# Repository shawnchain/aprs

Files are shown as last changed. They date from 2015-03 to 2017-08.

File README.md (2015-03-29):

# TinyAPRS - A cheap APRS TNC for HAM #

### What is TinyAPRS ###

Like most of the APRS TNCs, TinyAPRS is an AFSK1200 modem that decodes radio signals into AX25 data packets. TinyAPRS also supports KISS protocol, so you can use it with most of the APRS applications.

Unlike most of the APRS TNCs, tinyAPRS is VERY VERY CHEAP. It will only cost $10 to build one. That means you can build your own APRS IGATE or tracking beacon with very low cost.

TinyAPRS has good performance on decoding. 
Currently, it works perfectly with my GM300 radio and decodes packets successfully from OT++(The local Digipeater)/FTM350R(My Car) and other devices. Based on my test, it decodes 850+ records from WA8LMF APRS TestCD/Track1. 

### How did it work ###

TinyAPRS is built on the giants shoulder.

 - An ALC/Filter circut that is the same as OpenTracker used, which will  greatly improve the decode capability.(Thank you to BH4TDV for sharing the circut design)
 - A fine-tunned AFSK/AX25/KISS stack that runs on AVR chip with very small memory footprints. (Thank you to Mark Qvist for his MicroAPRS, but mine now is better :)
 - Good abstraction to the hardware with BertOS, which made it easy to port TinyAPRS firmware to other MCUs.

Technical specification 

 - Main Chip : ATMEL/ATMEGA328P (Cheap clones of Arduino ProMini, could be ported to other type of AVR MCUs with ease)
 - ALC circut: MCP6001 OPA
 - Firmware  : AFSK1200/KISS(P-CSMA)/AT Serial

### The License ###

TinyAPRS is released under GPL license, **but with the following restriction** :

 - Any person, who decide to use and/or get benefits from any part of the TinyAPRS project, will be obliged to send the author(me/BG5HHP/Shawn) a gift. (Any kind of gift will be fine but Beers/PostCards/Parts of HAM radios are preferred :)
 - No commercial use.
 - All GPL restrictions

### Pictures ###

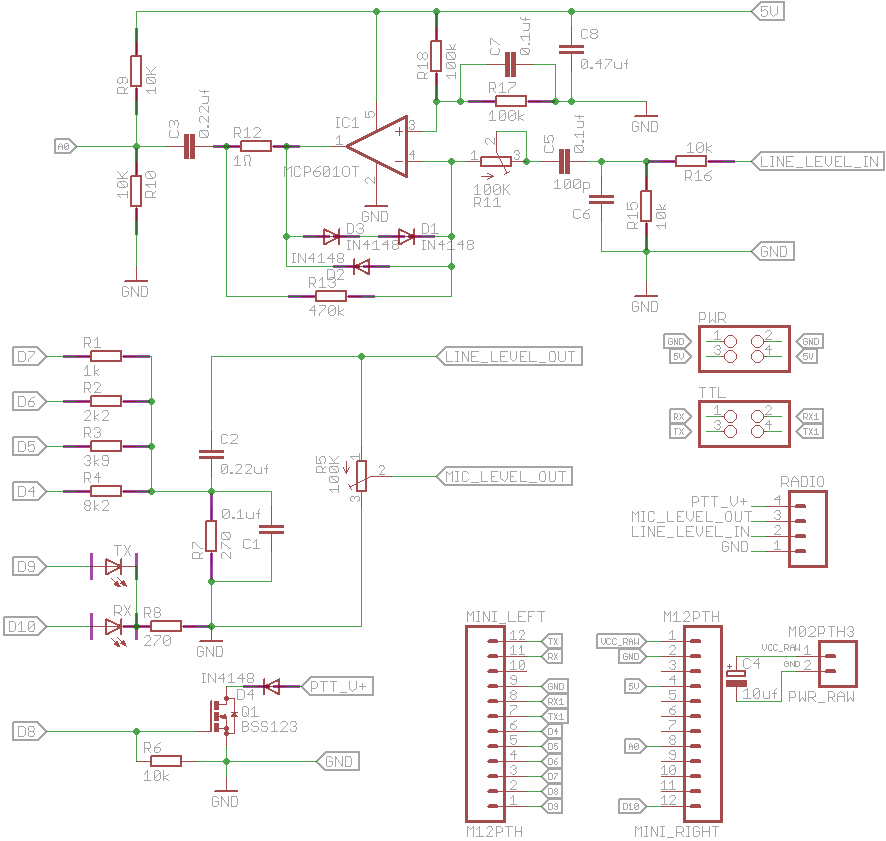
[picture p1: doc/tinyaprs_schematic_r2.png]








Please visit my [weibo album](http://www.weibo.com/p/1005052321043580/album?from=page_100505&mod=TAB#place "Weibo Album") for more pictures.

Cheers,

Shawn (BG5HHP)

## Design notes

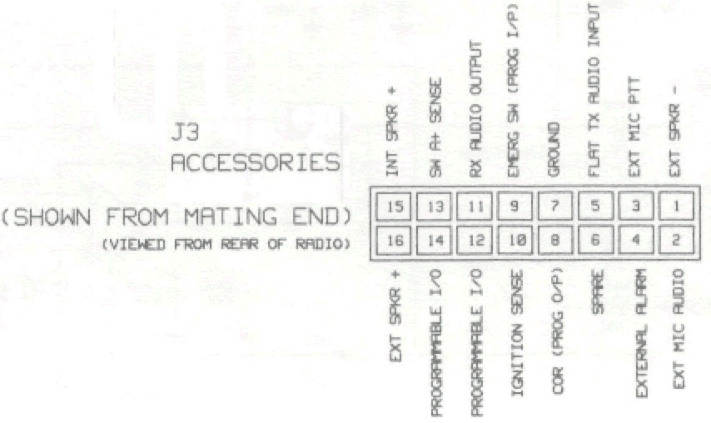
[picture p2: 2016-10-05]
doc/wiki/SM50_HOWTO/pinout_2.JPG

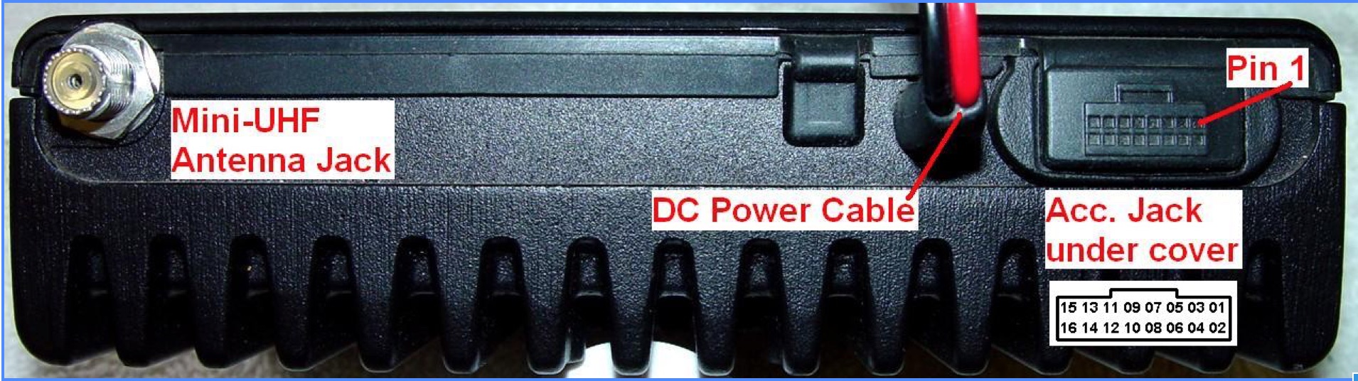
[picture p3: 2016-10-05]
doc/wiki/SM50_HOWTO/pinout_1.JPG

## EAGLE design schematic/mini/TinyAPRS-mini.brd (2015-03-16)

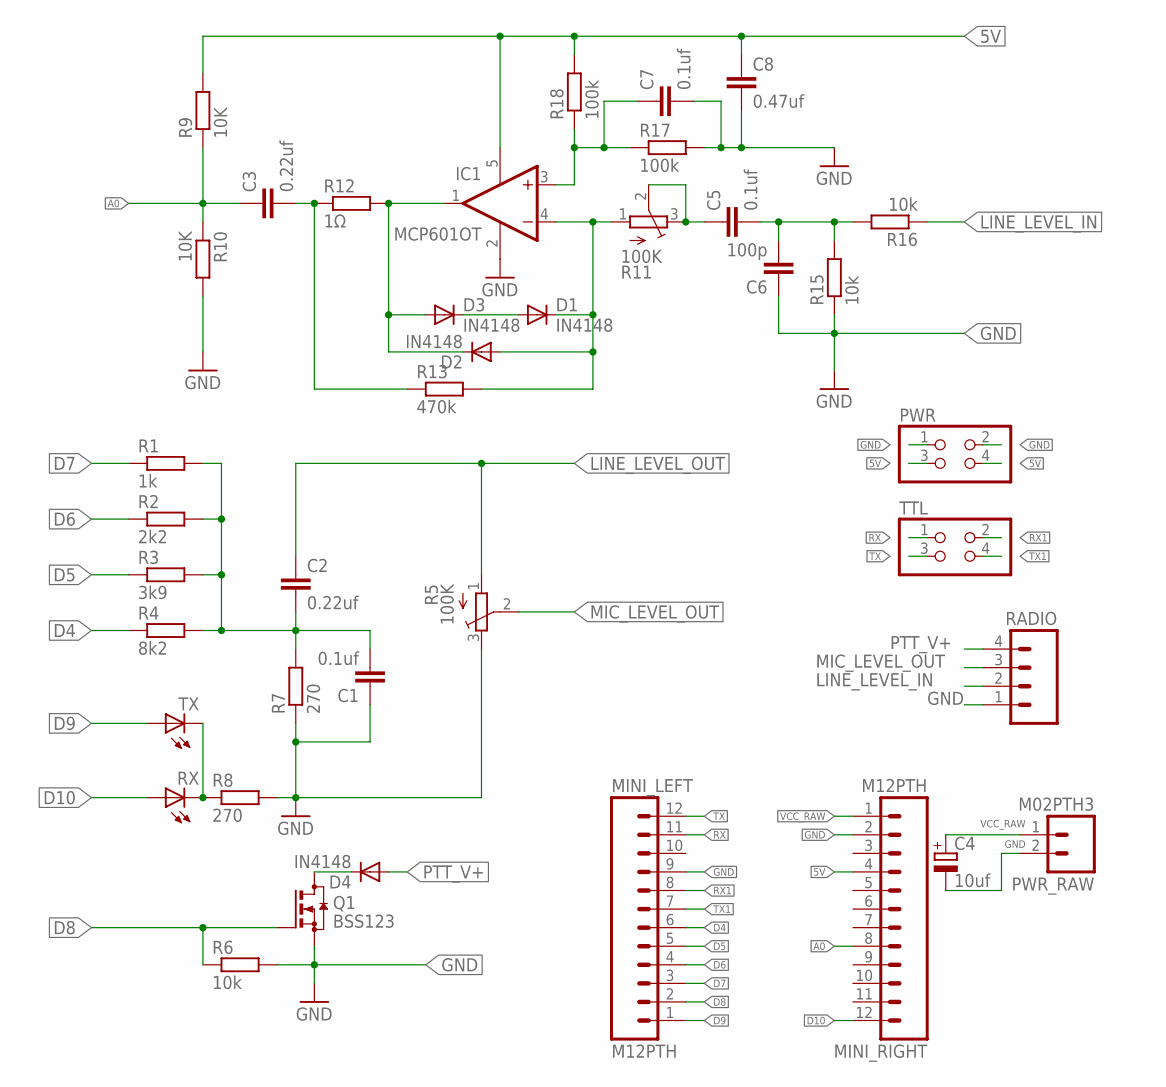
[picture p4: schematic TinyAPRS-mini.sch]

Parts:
C1, C5, C7: 0.1uf; C050-024X044
C2, C3: 0.22uf; C050-024X044
C4: 10uf; E2,5-5
C6: 100p; C050-024X044
C8: 0.47uf; C050-024X044
D1, D2, D3, D4: IN4148; D-2.5
IC1: MCP601OT; SOT23-5
MINI_LEFT: M12PTH; 1X12
MINI_RIGHT: M12PTH; 1X12
PWR: PINHD-2X2; 2X02
PWR_RAW: M02PTH3; 1X02_LONGPADS
Q1: BSS123; SOT23
R1: 1k; 0204/5
R2: 2k2; 0204/5
R3: 3k9; 0204/5
R4: 8k2; 0204/5
R5, R11: 100K; TC33X
R6, R15, R16: 10k; 0204/5
R7: 270; 0204/5
R8: 270; 0204V
R9, R10: 10K; 0204/5
R12: 1Ω; 0204V
R13: 470k; 0204/5
R17, R18: 100k; 0204/5
RADIO: M04PTH; 1X04
RX: LED_ELD260; LED_LD260
TTL: PINHD-2X2; 2X02
TX: LED_ELD260; LED_LD260

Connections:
5V: C8.1, IC1.5 (V+), MINI_RIGHT.4, PWR.3, PWR.4, R9.2, R18.2
A0: C3.1, MINI_RIGHT.8, R9.1, R10.1
D4: MINI_LEFT.6, R4.1
D5: MINI_LEFT.5, R3.1
D6: MINI_LEFT.4, R2.1
D7: MINI_LEFT.3, R1.1
D8: MINI_LEFT.2, Q1.1 (G), R6.1
D9: MINI_LEFT.1, TX.A
D10: MINI_RIGHT.12, RX.A
GND: C1.1, C4.-, C6.1, C7.2, C8.2, IC1.2 (V-), MINI_LEFT.9, MINI_RIGHT.2, PWR.1, PWR.2, PWR_RAW.2, Q1.2 (S), R5.3 (E), R6.2, R7.1, R8.2, R10.2, R15.1, R17.2, RADIO.1
LINE_LEVEL_IN: R16.1, RADIO.2
LINE_LEVEL_OUT: C2.1, R5.1 (A)
MIC_LEVEL_OUT: R5.2 (S), RADIO.3
unnamed: R8.1, RX.K (C), TX.K (C)
unnamed: D2.C, D3.A, IC1.1 (OUT), R12.2
unnamed: D1.C, D2.A, IC1.4 (-IN), R11.1 (A), R13.2
unnamed: D4.C, Q1.3 (D)
unnamed: C5.1, R11.2 (S), R11.3 (E)
unnamed: C5.2, C6.2, R15.2, R16.2
unnamed: C7.1, IC1.3 (+IN), R17.1, R18.1
unnamed: D1.A, D3.C
unnamed: C3.2, R12.1, R13.1
PTT_V+: D4.A, RADIO.4
RX: MINI_LEFT.11, TTL.1
RX1: MINI_LEFT.8, TTL.2
R_DAC: C1.2, C2.2, R1.2, R2.2, R3.2, R4.2, R7.2
TX: MINI_LEFT.12, TTL.3
TX1: MINI_LEFT.7, TTL.4
VCC_RAW: C4.+, MINI_RIGHT.1, PWR_RAW.1

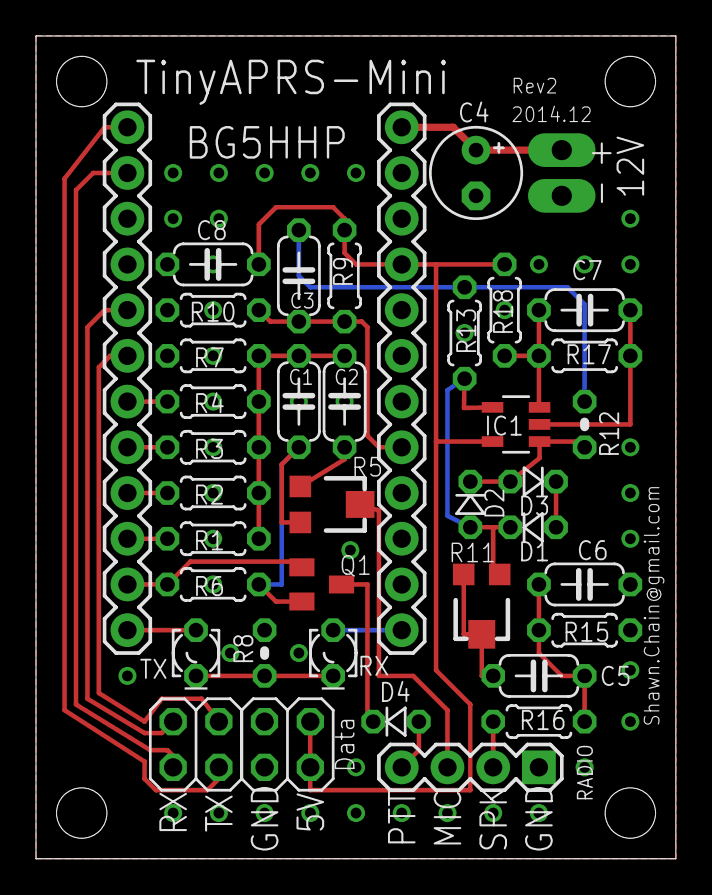
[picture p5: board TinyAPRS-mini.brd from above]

Board: 2 copper layers, 35.5 x 45.7 mm, 39 parts (0 on the bottom side), 29 nets.

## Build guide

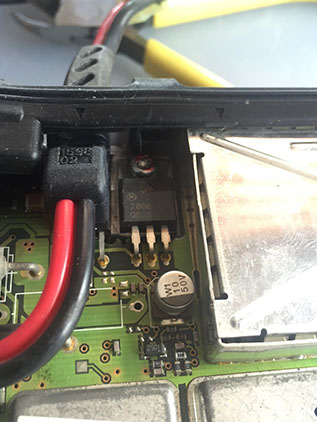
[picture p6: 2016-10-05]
doc/wiki/SM50_HOWTO/setup_3.JPG

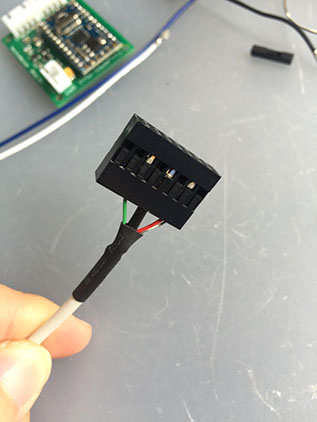
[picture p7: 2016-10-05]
doc/wiki/SM50_HOWTO/cable_2.JPG

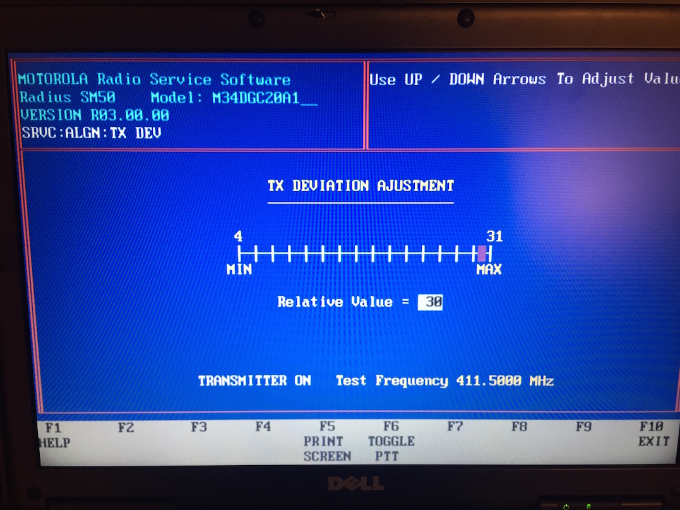
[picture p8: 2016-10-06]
doc/wiki/SM50_HOWTO/tx_setup_01.JPG

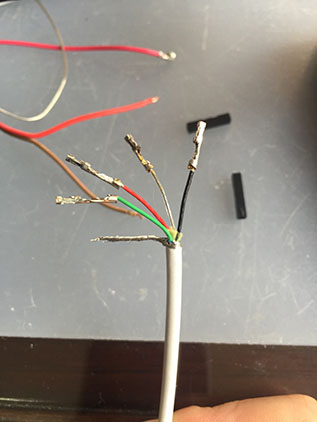
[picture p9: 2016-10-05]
doc/wiki/SM50_HOWTO/cable_1.JPG

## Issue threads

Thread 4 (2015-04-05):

kfile_getchar might stop working on serial read operation

shawnchain, 2015-04-05:
Found while debugging GPS input, mcu failed to read chars from GPS, switch to ser_getchar_nowait solves that problem. See reader.c inside for the current work-around.

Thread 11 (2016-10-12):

Replace the arduino pro mini bootloader for watchdog to work

shawnchain, 2016-10-12:
The arduino pro mini bootloader will cause a infinite loop after the watchdog reset is triggered. And re-power the chip is needed to recover.

See:
https://andreasrohner.at/posts/Electronics/How-to-make-the-Watchdog-Timer-work-on-an-Arduino-Pro-Mini-by-replacing-the-bootloader/

And the xboot seems pretty good alternate https://github.com/alexforencich/xboot

shawnchain, 2016-11-24:
Done

Closed 2016-11-24.

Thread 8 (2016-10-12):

I2C supports both master and slave mode

shawnchain, 2016-10-12:
Currently the I2C driver for avr only supports master mode with interrupt disabled.
Porting the twi.h/twi.c from Arduino Wiring library could be a start.

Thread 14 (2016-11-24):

Text message should be part of the whole beacon message

shawnchain, 2016-11-24:
Currently at+text will set the whole text message, which should be changed as:
Beacon Text = Symbol | Fixed Location|GPS Location + Text + Firmware Suffix.

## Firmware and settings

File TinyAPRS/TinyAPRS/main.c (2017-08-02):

/**
 * \file
 * <!--
 * This file is part of TinyAPRS.
 * Released under GPL License
 *
 * Copyright 2015 Shawn Chain (shawn.chain@gmail.com)
 *
 * -->
 *
 * \brief The main routines
 *
 * \author Shawn Chain <shawn.chain@gmail.com>
 * \date 2015-02-07
 */

#include <cfg/compiler.h>

#include <cpu/irq.h>
#include <cpu/pgm.h>     /* PROGMEM */
#if CPU_AVR
#include <avr/pgmspace.h>
#endif

#include <net/afsk.h>
#include <net/ax25.h>

#include <drv/ser.h>
#include <drv/timer.h>

#include <stdio.h>
#include <string.h>
#include <ctype.h>

#include "global.h"

#include "utils.h"

#include "settings.h"
#include "reader.h"

#if MOD_CONSOLE
#include "console.h"
#endif

#if MOD_KISS
#include <net/kiss.h>
#endif

#if MOD_DIGI
#include "cfg/cfg_digi.h"
#include "digi.h"
#endif

#if MOD_RADIO
#include "cfg/cfg_radio.h"
#include "radio.h"
#endif

#if MOD_TRACKER
#include "tracker.h"
#endif

#if MOD_BEACON
#include "cfg/cfg_beacon.h"
#include "beacon.h"
#endif

Afsk g_afsk;
AX25Ctx g_ax25;
Serial g_serial;
SerialReader g_serialreader;

#define ADC_CH 0
#define DAC_CH 0

// DEBUG FLAGS
#define DEBUG_FREE_RAM 0
#define DEBUG_SOFT_SER 0

typedef enum{
	MODE_CFG  = 0,
	MODE_KISS = 1,
	MODE_TRACKER = 2,
	MODE_DIGI = 3,
	MODE_TEST_BEACON = 0xf
}RunMode;
static RunMode currentMode = MODE_CFG;

///////////////////////////////////////////////////////////////////////////////////
// Callbacks
///////////////////////////////////////////////////////////////////////////////////

/*
 * callback when ax25 message received from radio
 */
static void ax25_msg_callback(struct AX25Msg *msg){
	switch(currentMode){
	case MODE_CFG:
		// Print received message to serial
		ax25_print(&(g_serial.fd),msg);
		break;

#if MOD_KISS
	case MODE_KISS:
		kiss_send_to_serial(0x00/*kiss port id*/,0x00,g_ax25.buf,g_ax25.frm_len - 2);
		break;
#endif

#if MOD_DIGI
	case MODE_DIGI:
		digi_handle_aprs_message(msg);
		break;
#endif

	default:
		break;

	}
}

/*
 * callback when kiss mode is end
 */
#if MOD_KISS
static void kiss_mode_exit_callback(void){
	currentMode = MODE_CFG;
	SERIAL_PRINT_P((&g_serial),PSTR("Exit KISS mode\r\n"));
}
#endif

#if MOD_BEACON
/*
 * callback when beacon mode is end
 */
static void beacon_mode_exit_callback(void){
	currentMode = MODE_CFG;
	SERIAL_PRINT_P((&g_serial),PSTR("Exit Beacon mode\r\n"));
}
#endif


///////////////////////////////////////////////////////////////////////////////////
// Command handlers
///////////////////////////////////////////////////////////////////////////////////

/*
 * AT+MODE=[0|1|2]
 */
static bool cmd_switch_mode(Serial* pSer, char* value, size_t len){
	bool modeOK = false;
	if(len > 0 ){
		int i = atoi(value);
		if(i == (int)currentMode && i == g_settings.run_mode){
			// already in this mode, bail out.
			return true;
		}

		modeOK = true;
		switch(i){
		case MODE_CFG:
			// Enter COMMAND/CONFIG MODE
			currentMode = MODE_CFG;
			g_ax25.pass_through = 0;		// parse ax25 frames
			ser_purge(pSer);  			// clear all rx/tx buffer
			SERIAL_PRINT_P(pSer,PSTR("Enter Config mode\r\n"));
			break;
#if MOD_KISS
		case MODE_KISS:
			// Enter KISS MODE
			currentMode = MODE_KISS;
			g_ax25.pass_through = 1;		// don't parse ax25 frames
			ser_purge(pSer);  			// clear serial rx/tx buffer
			SERIAL_PRINT_P(pSer,PSTR("Enter KISS mode\r\n"));
			break;
#endif

#if MOD_TRACKER
		case MODE_TRACKER:
			currentMode = MODE_TRACKER;
			kfile_printf_P((KFile*)pSer,PSTR("Enter Tracker mode\r\n"));
			kfile_flush((KFile*)pSer);
			ser_purge(pSer);
			// should enable the tracker/gps
			tracker_init_gps();
			break;
#endif

#if MOD_DIGI
		case MODE_DIGI:
			// DIGI MODE
			currentMode = MODE_DIGI;
			g_ax25.pass_through = 0;		// need parse ax25 frames
			SERIAL_PRINT_P(pSer,PSTR("Enter Digi mode\r\n"));
			break;
#endif
		default:
			// unknown mode
			modeOK = false;
			break;
		} // end of switch

		// save to settings/run_mode
		if(modeOK){
			if(currentMode != g_settings.run_mode){
				settings_set_params(SETTINGS_RUN_MODE,&currentMode,1);
				settings_save();
			}
		}else{
			SERIAL_PRINTF_P(pSer,PSTR("Invalid mode %s, [0|1|2|3] is accepted\r\n"),value);
		}
	}else{
		// no parameters, just dump the mode
		SERIAL_PRINTF_P(pSer,PSTR("Current mode %d/%d\r\n"),currentMode,g_settings.run_mode);
	}

	return true;
}

#if MOD_KISS
/*
 * AT+KISS=1 enter KISS mode, same as AT+MODE=1, where MODE_KISS = 1
 */
static bool cmd_enter_kiss_mode(Serial* pSer, char* value, size_t len){
	(void)value;
	(void)len;
	char c[] = "1"; //
	return cmd_switch_mode(pSer, c, 1);
}
#endif

static void check_run_mode(void){
	if(currentMode == g_settings.run_mode){
		return;
	}

	static ticks_t start = 0;
	ticks_t now = timer_clock_unlocked();
	if(start == 0){
		start = now;
	}else if(now -  start > ms_to_ticks(10000)){
		if(currentMode != g_settings.run_mode){
			char c[2];
			c[0] = (g_settings.run_mode + 48);
			c[1] = 0;
			cmd_switch_mode(&g_serial,c,1);
		}
	}
}

static void init(void)
{

    IRQ_ENABLE;

	kdbg_init();
	timer_init();

	/* Initialize serial port, we are going to use it to show APRS messages*/
	ser_init(&g_serial, SER_UART0);
	ser_setbaudrate(&g_serial, SER_DEFAULT_BAUD_RATE);
    // For some reason BertOS sets the serial
    // to 7 bit characters by default. We set
    // it to 8 instead.
    UCSR0C = _BV(UCSZ01) | _BV(UCSZ00); // see ATMEGA328P datasheet P197, Table 20-11. UCSZn Bits Settings

    // initialize the reader that wraps the serial
    serialreader_init(&g_serialreader, &g_serial);

    // Load settings first
    settings_load();

	/*
	 * Init afsk demodulator. We need to implement the macros defined in hw_afsk.h, which
	 * is the hardware abstraction layer.
	 * We do not need transmission for now, so we set transmission DAC channel to 0.
	 */
	afsk_init(&g_afsk, ADC_CH, DAC_CH);

	/*
	 * Here we initialize AX25 context, the channel (KFile) we are going to read messages
	 * from and the callback that will be called on incoming messages.
	 */
	ax25_init(&g_ax25, &g_afsk.fd, ax25_msg_callback);
	g_ax25.pass_through = false;

	// Initialize the kiss module
	// NOTE - use shared memory buffer
#if MOD_KISS
	kiss_init(&g_serialreader,&g_ax25);
#endif

#if MOD_BEACON
	// Initialize the beacon module
    beacon_init(beacon_mode_exit_callback);
#endif

    // Initialize the digi module
#if MOD_DIGI
    digi_init();
#endif

#if MOD_RADIO
    // Initialize the soft serial and radio
    radio_init(4310400); //TODO read from settings
#endif

    // Initialize GPS NMEA/GPRMC parser
#if MOD_TRACKER
    tracker_init();
#endif

#if MOD_CONSOLE
    //////////////////////////////////////////////////////////////
    // Initialize the console & commands
    console_init();
    console_add_command(PSTR("MODE"),cmd_switch_mode);			// setup tnc run mode
#if MOD_KISS
    console_add_command(PSTR("KISS"),cmd_enter_kiss_mode);		// enable KISS mode
#endif
#endif
}


int main(void){
	init();

	while (1){
		/*
		 * This function will look for new messages from the AFSK channel.
		 * It will call the message_callback() function when a new message is received.
		 * If there's nothing to do, this function will call cpu_relax()
		 */
		ax25_poll(&g_ax25);

		check_run_mode();

		switch(currentMode){
			case MODE_CFG:
#if MOD_CONSOLE
				console_poll();
#endif
#if MOD_BEACON
				beacon_broadcast_poll();
#endif
				break;
#if MOD_TRACKER
			case MODE_TRACKER:
				tracker_poll();
				break;
#endif

#if MOD_KISS
			case MODE_KISS:{
				kiss_poll();
				break;
			}
#endif

#if MOD_DIGI
			case MODE_DIGI:{
				console_poll();
				beacon_broadcast_poll();
				break;
			}
#endif

			default:
				break;
		}// end of switch(runMode)

#if DEBUG_FREE_RAM
		{
			static ticks_t ts = 0;

			if(timer_clock_unlocked() -  ts > ms_to_ticks(5000)){
				ts = timer_clock_unlocked();
				uint16_t ram = freeRam();
				SERIAL_PRINTF((&g_serial),"%u\r\n",ram);
			}
		}
#endif
#if DEBUG_SOFT_SER
		// Dump the isr changes
		{
			SoftSerial *softSer = radioPort;
			static uint32_t i = 0;
			//static uint32_t j = 0;
			if(i++ == 30000){
				i = 0;

				char c;
				while(softser_avail(softSer)){
					c = softser_read(softSer);
					kfile_putc(c,&(g_serial.fd));
				}
				char buf[8];
				sprintf_P(buf,PSTR("0K\n\r"));
				softser_print(softSer,buf);
			}
		}
#endif

	} // end of while(1)
	return 0;
}

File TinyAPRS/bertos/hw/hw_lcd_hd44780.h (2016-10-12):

/**
 * \file
 * <!--
 * This file is part of BeRTOS.
 *
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
 * As a special exception, you may use this file as part of a free software
 * library without restriction.  Specifically, if other files instantiate
 * templates or use macros or inline functions from this file, or you compile
 * this file and link it with other files to produce an executable, this
 * file does not by itself cause the resulting executable to be covered by
 * the GNU General Public License.  This exception does not however
 * invalidate any other reasons why the executable file might be covered by
 * the GNU General Public License.
 *
 * Copyright 2003, 2004, 2005, 2008 Develer S.r.l. (http://www.develer.com/)
 * Copyright 2001 Bernie Innocenti <bernie@codewiz.org>
 *
 * -->
 *
 * \brief LCD low-level hardware macros
 *
 * \author Bernie Innocenti <bernie@codewiz.org>
 * \author Stefano Fedrigo <aleph@develer.com>
 *
 */

#ifndef HW_LCD_HD44780_H
#define HW_LCD_HD44780_H

#include "cfg/cfg_lcd_hd44780.h"  /* CONFIG_LCD_4BIT & CONFIG_LCD_I2C */

#include <cpu/types.h>
#include <cpu/irq.h>


#if CONFIG_LCD_I2C

#include <drv/pcf8574.h>

#define PCF8574_DEVICEID  0 //device id, addr = pcf8574 base addr + PCF8574_DEVICEID


// make sure we are in 4 bit mode for i2c
#ifdef CONFIG_LCD_4BIT
#undef CONFIG_LCD_4BIT
#define CONFIG_LCD_4BIT 1
#endif

#define LCD_DATA0_PIN    4            /**< pin for 4bit data bit 0     */
#define LCD_DATA1_PIN    5            /**< pin for 4bit data bit 1     */
#define LCD_DATA2_PIN    6            /**< pin for 4bit data bit 2     */
#define LCD_DATA3_PIN    7            /**< pin for 4bit data bit 3     */
#define LCD_RS_PIN       0            /**< pin  for RS line            */
#define LCD_RW_PIN       1            /**< pin  for RW line            */
#define LCD_E_PIN        2            /**< pin  for Enable line        */
#define LCD_LED_PIN      3            /**< pin  for Led                */
#define LCD_LED_POL      1            /**< polarity of Led pin (1=+ve) */


volatile uint8_t dataport = 0;

/*
** local functions
*/



/* toggle Enable Pin to initiate write */
static void
lcd_e_toggle (void)
{
   pcf8574_setoutputpinhigh (PCF8574_DEVICEID, LCD_E_PIN);
   timer_udelay (1);;
   pcf8574_setoutputpinlow (PCF8574_DEVICEID, LCD_E_PIN);
}


/*************************************************************************
Low-level function to write byte to LCD controller
Input:    data   byte to write to LCD
          rs     1: write data    
                 0: write instruction
Returns:  none
*************************************************************************/
static void
lcd_write (uint8_t data, uint8_t rs)
{
   if (rs)                      /* write data        (RS=1, RW=0) */
      dataport |= BV (LCD_RS_PIN);
   else                         /* write instruction (RS=0, RW=0) */
      dataport &= ~BV (LCD_RS_PIN);
   dataport &= ~BV (LCD_RW_PIN);
   pcf8574_setoutput (PCF8574_DEVICEID, dataport);

   /* output high nibble first */
   dataport &= ~BV (LCD_DATA3_PIN);
   dataport &= ~BV (LCD_DATA2_PIN);
   dataport &= ~BV (LCD_DATA1_PIN);
   dataport &= ~BV (LCD_DATA0_PIN);
   if (data & 0x80)
      dataport |= BV (LCD_DATA3_PIN);
   if (data & 0x40)
      dataport |= BV (LCD_DATA2_PIN);
   if (data & 0x20)
      dataport |= BV (LCD_DATA1_PIN);
   if (data & 0x10)
      dataport |= BV (LCD_DATA0_PIN);
   pcf8574_setoutput (PCF8574_DEVICEID, dataport);
   lcd_e_toggle ();

   /* output low nibble */
   dataport &= ~BV (LCD_DATA3_PIN);
   dataport &= ~BV (LCD_DATA2_PIN);
   dataport &= ~BV (LCD_DATA1_PIN);
   dataport &= ~BV (LCD_DATA0_PIN);
   if (data & 0x08)
      dataport |= BV (LCD_DATA3_PIN);
   if (data & 0x04)
      dataport |= BV (LCD_DATA2_PIN);
   if (data & 0x02)
      dataport |= BV (LCD_DATA1_PIN);
   if (data & 0x01)
      dataport |= BV (LCD_DATA0_PIN);
   pcf8574_setoutput (PCF8574_DEVICEID, dataport);
   lcd_e_toggle ();

   /* all data pins high (inactive) */
   dataport |= BV (LCD_DATA0_PIN);
   dataport |= BV (LCD_DATA1_PIN);
   dataport |= BV (LCD_DATA2_PIN);
   dataport |= BV (LCD_DATA3_PIN);
   pcf8574_setoutput (PCF8574_DEVICEID, dataport);
}


/*************************************************************************
Low-level function to read byte from LCD controller
Input:    rs     1: read data    
                 0: read busy flag / address counter
Returns:  byte read from LCD controller
*************************************************************************/
static uint8_t
lcd_read (uint8_t rs)
{
   uint8_t data;

   if (rs)                      /* write data        (RS=1, RW=0) */
      dataport |= BV (LCD_RS_PIN);
   else                         /* write instruction (RS=0, RW=0) */
      dataport &= ~BV (LCD_RS_PIN);
   dataport |= BV (LCD_RW_PIN);
   pcf8574_setoutput (PCF8574_DEVICEID, dataport);

   pcf8574_setoutputpinhigh (PCF8574_DEVICEID, LCD_E_PIN);
   timer_udelay (1);;
   data = pcf8574_getoutputpin (PCF8574_DEVICEID, LCD_DATA0_PIN) << 4; /* read high nibble first */
   pcf8574_setoutputpinlow (PCF8574_DEVICEID, LCD_E_PIN);

   timer_udelay (1);;              /* Enable 500ns low       */

   pcf8574_setoutputpinhigh (PCF8574_DEVICEID, LCD_E_PIN);
   timer_udelay (1);;
   data |= pcf8574_getoutputpin (PCF8574_DEVICEID, LCD_DATA0_PIN) & 0x0F; /* read low nibble        */
   pcf8574_setoutputpinlow (PCF8574_DEVICEID, LCD_E_PIN);

   return data;
}

/*************************************************************************
Set illumination pin
*************************************************************************/
void
lcd_backlight (uint8_t onoff)
{
   if ((onoff ^ LCD_LED_POL) & 1)
      dataport &= ~BV (LCD_LED_PIN);
   else
      dataport |= BV (LCD_LED_PIN);
   pcf8574_setoutput (PCF8574_DEVICEID, dataport);
}
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

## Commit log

2014-10-14 Add LCD4884 driver
2015-02-08 ax25 driver supports pass_through mode.
2015-02-13 Refactored to: extract beacon module; support KISS/COMMAND mode switch
2015-02-19 Suports print string from PROGMEM to save runtime ram
2015-02-20 Refactor KISS module to work with other modules that shares one UART
2015-02-28 Add print_size and flash target to the makefile
2015-03-07 soft reboot device after settings are cleared.
2015-03-08 don't print ssid 0
2015-03-08 print received ax25 message in TNC2-stye format in normal mode.
2015-03-16 Add schematic for the mini board
    [TinyAPRS-mini.brd, TinyAPRS-mini.sch]
2015-03-30 modify ax25 to print message count when CONFIG_AX25_DEBUG_PRINT_MESSAGE_COUNT = 1
2015-03-30 supports tracker mode. currently use AT+MODE=2 to enable
2015-03-31 run_mode now will be saved to settings and device automatically enter even after reboot.
    [main.c]
2015-03-31 check_run_mode bugfix in main loop
    [main.c]
2015-04-01 beacon dst callsign bugfix
    [main.c]
2015-04-02 Bugfix on GPS receiving.
    [main.c]
2015-04-05 light on gps indicator LED inside gps mdoule.
2015-04-14 remove debug printf in digi module.
2016-10-05 Add pin setup image
2016-10-10 uart drv optimized
2016-10-12 Upgrade bertos drivers to g8ecj's bertos fork
2016-10-12 issue #1 optimized the kfile_printf_P() to save 120 bytes of sram
    [main.c]
2016-10-13 digi module includes the counter, optimize the printf_P call
2016-10-17 add wdt_init() to avoid infinite loop for NO_BOOTLOADER case
2016-10-26 Add crc field in kiss/settings response frame
2016-11-04 Fixed compile broken issue
    [main.c]
2017-02-04 Correct the NRZ-S coding in AFSK, which is used by APRS/HDLC/BELL202. Fixes the IIR filter cutoff frequency to about 1200HZ
    [afsk.c]
2017-02-04 Minor changes on filter cutoff frequency
2017-08-02 The radio board support
2017-08-02 refine arduino pin headers
2018-06-13 Update device TOCALL to APTBxx assigned by WB4APR

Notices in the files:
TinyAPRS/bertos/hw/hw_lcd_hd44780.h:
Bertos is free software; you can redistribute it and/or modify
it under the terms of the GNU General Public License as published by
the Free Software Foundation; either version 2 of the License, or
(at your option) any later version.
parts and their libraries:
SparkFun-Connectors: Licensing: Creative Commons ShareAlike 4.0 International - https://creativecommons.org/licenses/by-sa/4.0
